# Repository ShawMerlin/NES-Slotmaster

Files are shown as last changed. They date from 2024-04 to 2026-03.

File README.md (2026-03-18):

06/25/2024 <br>
- Laser Bear has made an incredible interconnect flex cable.  I invite all to check this out!! <br>
- https://www.laserbear.net/products/nes-slotmaster
- https://x.com/dubesinhower/status/1805235309203845310/photo/1 <br>


 <br> <br>
06/15/2024 <br>
- We have a new solution that is 100% based upon J D'Silva's Ampersand Board. <br>
- J D'Silva was kind enough to let his design be used for our solution.  Give this guy some love!! https://twitter.com/jdsilva <br>
- No Longer Available from PCBWay (3/18/2026)

 <br>

 <br>

 <br>
 <br>
05/31/2024 <BR>
- 2 solutions have been developed and are currently being tested.  If you would like to help with the testing, please reach out through email. <BR>
- Laser Bear developed a [Flex cable](https://twitter.com/collingall/status/1795501525734768719) for the interconnect which allows better GND Coupling of the signal traces. <BR>
- J D'Silva developed a [interconnect board](https://github.com/J-DSilva/NES-Ampersand) which will also provide better GND Coupling. <BR>
- Check out the [Ninten-Drawer](https://twitter.com/RockerGameMod/status/1784955436606673254) as well for an alternative solution that solves the death grip issue in a very unique way. <BR>

J D'Silva's NES Amerpsand's solution means you do not have to replacet he current PCB's if you have already ordered them. <BR>
If you are a DIYer, this solution will be the most cost effective while Laser Bears solution is very elegant if you are not into DIY. <BR>

Here is some of my work with J D'Silva's NES Ampersand




 <BR>
 <BR>

05/17/2024 <BR>
- We are aware of potential issues with some EverDrive N8 Pro CARTs and the Slotmaster. <br>
- Issues can range from freezing, graphical artifacts and just plain refusing to boot. <br>
- It seems to be Hit or Miss when it comes to folks Everdrives. We have lots of reports of some working fine. <br>
- We are working on a solution so that more Everdrives will work.  More to come. <br> <br>

05/01/2024 <BR>
- New FPC Flex Slotmaster PCB Annoucement.  There is a seperate folder now for Flex version vs DIY Version. <br>
- Both Flex and DIY Versions have added footprints for ATTiny so a Krikzz AVRCIC can be used (if desired) <BR>
- DIY Version now has a 8 pin breakout that will help connect all 72 pins. (if desired) <br> <br>

04/22/2024 <BR>
- New Version 1.8 Board that ensures better game compatibility. Gerbers Above<br>
- We have a quick fix for anyone with that wants better compatibity with the V1.7 Board <br>
  This issue will not impact the majority of NES Game titles out there, but could impact a few. <BR>
  https://github.com/ShawMerlin/NES-Slotmaster/blob/main/Slotmaster%20DIY%20Version/Better_Compatibility_Fix.md <BR> <BR>

04/17/2024 <BR>
- FAQ information on the recent 3D Model and PCB change <br>
https://github.com/ShawMerlin/NES-Slotmaster/blob/main/SlotMaster_April_17th_Information_Update.pdf  <br>
- The Gerbers have been taken off Github as there is a small change that needs to be further researched. <BR>
- This change will not impact the majority of NES Game titles out there, but could impact a few. <BR>
- I plan to have everything tested and the new Gerbers released later this week  <BR>
- New SMD FPC Ribbon PCBs should arrive this week.  This design passes through all 72 pins. <BR>
- Laser Bear was gracious enough to share his changes to the 3d Model to provide more support.  This is V9 above <BR> <BR>

# NES Slotmaster

A fully open-sourced drop in replacement for the 72 Pin Cartridge Slot on a Front Loader NES. <BR> <BR>
if downloading Gerbers and STL is not your thing, both of these are included in my PCBWay Project. <BR>
https://www.pcbway.com/project/shareproject/NES_Slotmaster_bc9ea5b8.html <BR>
https://www.pcbway.com/project/shareproject/NES_Slotmaster_3D_Base_02da723d.html <BR> <BR>

Laser Bear is also offering these pre-ordered as a kit from his website <BR>
https://www.laserbear.net/products/nes-slotmaster <BR>

 <BR>
# Features of the NES Slotmaster
- Open sourced, build it yourself, make changes, the world is your burrito. <BR>
- No modification is need to your NES Console. Just enough skill to remove the top portion and swap the connector. <BR>
- Uses an existing 72 pin Connector. (Designing a brand new connector is not in my wheelhouse) <BR>
- The NES Cartridge is held close to the door of the NES so it's easy to grab and remove from the console. <BR>
- Minimul components, this can be built for less than $20. <BR>
- PCB uses a through hole design so this will be easier to solder for beginners.  I great first project. <BR>
- Can be used with the RF Shielding on the top and the bottom if desired, there is plenty of clearance. <BR>

<Br>
The 3D Model for this design was influenced by malleetech123 on Thingiverse and built using Autodesk Fusion 360. <BR>
I recommend using 100% in-fill with FDM printing for strength or print in resin. <BR>
A design using FPC Cables is in the works, it won't be as beginner friendly but will have less holes to solder. <BR>
<Br>
<Br>
















<br>
Clearance of the top and bottom shield <Br>







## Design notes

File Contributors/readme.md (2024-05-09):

# Contributors <br> <br>

Below is everyone that helped with the development of the Slotmaster.   Please show them all some love!! <br> <br>

- George from Long Island Retro Gaming for helping test the design. <br>
    https://www.youtube.com/@LIRetroGaming/videos <br>
 <br> <br>
- Project Guardian for being my design partner and my voice of reason. <br>
     <br> <br>
- Greg from Laser Bear for improving the 3D Model and offering DIY Kits <br>
    https://www.laserbear.net/products/nes-slotmaster <br>
     <br> <br>
- Muramasa for providing a slick easy to read schematic. <br>
    https://www.muramasaentertainment.com/ <br>
    
 <br>

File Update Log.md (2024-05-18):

## Known Issues <BR>
Certain Everdrive N8's are not booting or booting with graphical issues. (5/14/2024) <br>
- This is impacted with the V1.8 board versions. <br>
- The issue is not due to the 8 expansion pins on the header cable. That was incorrect information applied to the silkscreen. <br>
- This is currently being researched to find the differences and what the root cause of this. <br>
- ~~Potentially a Power draw issue with the size of the traces~~, also might be related to the ribbon cable being too long. <br>
- Potential of an issue with Noise/EMI getting into the data signal.  We are currently working on improving GND Coupling. <br>
- Some Everdrives N8 Pro's are working fine without issue.  We are keeping track of the ratio while we work on a solution.<br> <br>

Some cartridges are not compatible <br>
- https://github.com/ShawMerlin/NES-Slotmaster/blob/main/GamesNotCompatible.md <br>

Slotmaster V1.7 doesn't connect Pin56 <br>
- https://github.com/ShawMerlin/NES-Slotmaster/blob/main/Slotmaster%20DIY%20Version/Better_Compatibility_Fix.md <br> <br>

## Flex Version 1.8b <BR>
On Hold until Everdrive Issue is resolved. <br>
- Uses SMD FPC Flex connectors so that flat cables can be used.  Far less soldering. <br>
- Has a footprint for a ATTiny13 so the Krikzz AVRCIC can be used (if desired). <br> <br>

## DIY Version 1.8d <BR>
Gerber Files are available the under Slotmaster DIY Version folder <br>
- Includes the 8 pin breakout of all expansion ports so all 72 pins can be connected <br>
- Has a footprint for a ATTiny13 so the Krikzz AVRCIC can be used (if desired). <br> <br>

## Version 1.8 <BR>
Released 04/22/2024 <BR>
- Connected Pins 15 (IRQ) and 56 (PPU-WR) to ensure 100% Game Compatibility <br>
- Added an 8 Pin Header (2x4) to the top and bottom board to connect the EXP ports (if needed) <br>
- Increased the trace size on the VCC & GND from .25mm to .5mm <br>
- Added a logo for Laser Bear who helped redesign the Cartridge Slot and who is also offering these kits for sale <br>
<BR> <BR>

## Version 1.7 <BR>
Released 03/31/2024 <BR>
- First Public Release <br>

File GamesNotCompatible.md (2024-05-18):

A recent issue with some games has been identified by [Aaron Perkins](https://github.com/aaronperkins) <br>
This shows certain games could have a type of cartridge which does not exetend the entire width of the pad to the edge. <br>
Instead, it goes down to a small trace that does not come into contact with the 72 pin connector. <br> <br>
This new cartridge style seems to be on later cartridges and might have had the shorter contacts to ensure the Power/GND pins contacted first. <br>
The little tail on the end is a result of the electroplating process and didn't have any impact on cartridge connections. <br> <br> 
Thank you to [RedHerring32](https://github.com/Redherring32) for the additional info <br>
<br>
A potential fix might be to cut off the tabs on both sides of the top 72 pin connector, the tabs the screws hold down.  <br>
I do caution though that without those tabs, more stress will be applied to the solder joints on the backs pins when pulling out cartridges. <br>
The Juice might not be worth the squeeze <br>
<br>
If you find one of these games, please reach out ot me so that I can include it on this page. <br>
<br>
List of known games that could have this cartridge <br>
- Some variations of Super Mario Brothers/Duck Hunt <br>
- Dragon Warrior (We have had 2 reports, 1 with the short pads and one with normal pads.) <br>
- Donkey Kong CLassic (1 report so far)
- 1942 (1 report so far)
- Adventures of Dino Riki (1 report so far)

<br>
Example of this type of cartridge <br>
 <br>
<br>

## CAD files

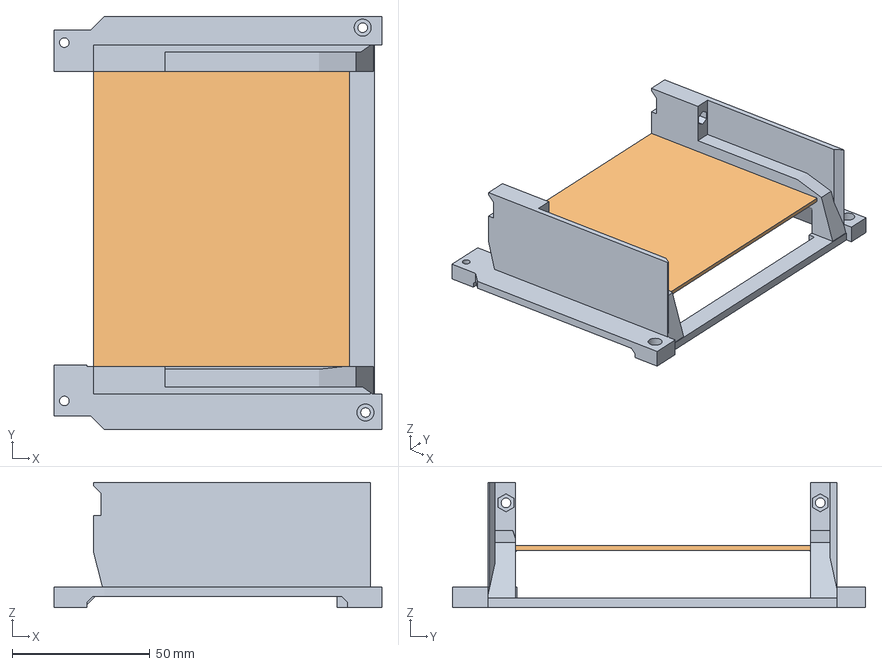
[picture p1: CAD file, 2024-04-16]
3D Model - NES Slotmaster (v9).3mf
119.0 x 150.0 x 45.5 mm
NES Slotmaster
Slotmaster bottom Cover

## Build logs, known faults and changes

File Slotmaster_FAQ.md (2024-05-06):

## Are these available for Pre-Order? <br>
Many people have reached out asking if they can sell these.  The MIT License allows for this to be sold. <br>
included in those people is Laser Bear who is taking Pre-Orders currently from his store <br>
https://www.laserbear.net/products/nes-slotmaster <br> <br>

## Can this be used with all the NES Shielding? <br>
Yes, A major part of this project was to get it to work perfectly with the shielding.  There is plenty of clearance. <br> <br>

## Why is there now a v1.8 SlotMaster PCB?
The SlotMaster v1.8 PCB corrects 2 pins, these were not used in v1.7 and should have been considered. With v1.8, now all NTSC NES Games will work with 100% compatibility. <br> <br>

## Is the Slotmaster V1.7 PCB still valid <br>
The v1.7 Slotmaster is still valid, it's just not 100% compatible with every single NES Game on the market.  <br>
We feel it's still valid as it will work with the majority of NES NTSC Titles. Onl<br>
If better compatibility is desired, please follow the 2 wire instruction guide that we will be providing soon. <br> <br>

## How can I get updates on new developments with this project <br>
In Github, you can click the watch button under the Slotmaster page. <br>
This will send you an email alert if any updates are maded to this repository. <br> <br>

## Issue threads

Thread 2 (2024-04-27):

1.7 fix instructions unclear

aaronperkins, 2024-04-27:
Love this project but I'm struggling with the 1.7 fix.

The schematic shows pin 15 to 29 but the photos show pin 15 to 27. Which is it? Also are we required to cut a trace? The schematic seems to indicate that, but it's not in the written instructions.

Thanks!

ShawMerlin, 2024-04-27:
The trace cut is not required as it's connected to a Expansion port pin.

You are correct that the pin I have marked and soldered to in my real life photo's is Pin 27 and wrong.  This should be on the one next to it.  Pin 15 is the IRQ which hardly any of North America NES's.  I will get the photo's updated to show the correct pin.

The critical one is pin 56 on the 72 pin connected to pin 32 on the 64 pin connector.
This is the PPU /WE and is the cause of the garbage artifacts that appear on some of the NES Games.

Thank you for pointing this out and i will get this corrected tonight.  Please follow the schematic and not the real life picture.

Thanks,
-Merlin Shaw

ShawMerlin, 2024-04-27:
Instructions have been corrected to show Pin 29 in the real photo's and not Pin 27.
Thank you again for finding this and raising the alarm.  :)

Closed 2024-04-27.

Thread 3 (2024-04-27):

Can't get some versions of Super Mario Duck Hunt to boot

aaronperkins, 2024-04-27:
I have quite a few copies of Super Mario Duck Hunt (don't ask why). I've been having trouble getting some to load with the Slotmaster. I get blinking light or character ROM corruption. Classic signs of a bad pin connection. The games are clean and known to work obviously.

I've narrowed it down to the versions of the game that have the weird "L" shaped pins. These are very common with later revisions of the game. See the attached picture.
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

I'm using the recommended 72 pin connector from Aliexpress. My guess is there is some sort of physical compatibility issue? The pins are too short to make proper contact with the connector?

I think I have other games beside SMBDH that have similar pins so I'm going to keep troubleshooting to verify the issue, but I wanted to bring it up here in case someone has run into this or knows better.

ShawMerlin, 2024-04-27:
Thank you for reaching out and providing the pictures.

Have you been able to look through and perform the 100% capability fix on
your Slotmaster  pcb’s?

I’m curious if some copies of duct hunt use the PPU /WE pin which is not
connected properly on the 1.7 version of Slotmaster.

If you have done the compatibility fix and still seeing this issue, please
reach out to my email. Merlin (dot) Shaw att gmail.

Thanks,
-Merlin Shaw

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

ShawMerlin, 2024-04-27:
Here is a link to the 100% compatibility fix

https://github.com/ShawMerlin/NES-Slotmaster/blob/main/Board%20V1.7%20100%25%20Compatibility%20Fix.md

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

ShawMerlin, 2024-04-27:
Doing some research on these carts with the L pads.  It does seem that Nintendo changed the carts in order to counter the clone units that were being developed.  Since we did not design that 72 pin connector, there might not be a solution for games with the L pads.

I would still check pin 15 & 56 on the CART to see if they are present or not.

aaronperkins, 2024-04-27:
Yeah I did the compatibly fix 1st thing. Didn't help. Nintendo messing with the pad design to stop counterfeit sounds like something they would do. I wonder if there are 72 pin connectors that work. I'll have to do some research. Thanks!

ShawMerlin, 2024-04-27:
If you do find any other 72 pin connectors out there, please reach out and
let us know.
The biggest issue is they have to be 2.5mm pitch while most connectors out
there are 2.54mm pitch.

So it has been very hard to find something compatible and I think we are
lucky enough to have these AliExpress ones.
But I am always 100% open to better options so if you find something.  Ring
the bell.  :)

Thanks,
-Merlin Shaw

On Sat, Apr 27, 2024 at 11:00 AM Aaron Perkins ***@***.***>
wrote:

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

aaronperkins, 2024-04-27:
Found a other game with short pads that won't work. This one is Dragon Warrior.
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

I confirmed with a multimeter no continuity between the short pads and the connector.

ShawMerlin, 2024-04-27:
Do you believe it’s every Dragon Warrior game cartridge or just the later
ones sold?

I can start a list of non compatible games on th le GitHub just so people
can realize that it’s not 100% compatible.

Thanks,
-Merlin Shaw

On Sat, Apr 27, 2024 at 4:13 PM Aaron Perkins ***@***.***>
wrote:

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

aaronperkins, 2024-04-27:
I have two copies of Dragon Warrior and they both have the same board with the short pads.

ShawMerlin, 2024-04-27:
I am going to get a coo of Dragon warrior to help visualize this for
myself.  Most likely there won’t be a solution quickly but I will add this
game to the potential issue list.

Thanks,
-Merlin Shaw

On Sat, Apr 27, 2024 at 5:42 PM Aaron Perkins ***@***.***>
wrote:

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

aaronperkins, 2024-04-28:
Found this potential solution. Going to try it when I have a chance.
[https://github.com/sanni/cartreader/issues/632](Link)

elgarlic, 2024-05-02:
Just out of curiosity, do these PCBs work in a Game Genie? Wondering for the sake of a stopgap fix (if it works) as well as whether this was another possible motivation for the design (if it doesn't).

aaronperkins, 2024-05-10:
Quick update.

Cutting the tabs off the 72 pin connector does seem to fix the issue, though I still wouldn't call the connection perfect. Sometimes the cart needs a little wiggle to get it working. Here are some pictures:

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

I used the tabs I cut off to space the screws otherwise they were now too long.

The game genie does also solve the problem as a work around:
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

You can see the game genie's connector allows the cart to slide back more compared to the slotmaster.

Finally I found another game with the same issue:
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
This one is Donkey Kong Classics

ShawMerlin, 2024-05-10:
thank you @aaronperkins for the pictures and analysis!! I will update our known issue document with Donkey Kong Classics as could be susceptible.

Interesting observation with cutting off the tabs, I should get my Dragon Warrior NES Cartridge this weekend and hope to get one of these short pad styles.

I will add your notes that cutting that tab might help.  I still wonder though if it's worth the effort when that tab having the screw hold it tight, helps the connector not pull so much on the back soldered pins.  Without that extra support, it might lead to some solder joints breaking in the future.  Just something to consider.

Thanks again!!

aaronperkins, 2024-05-10:
I have an old NES on my bench I use to test games. It gets a lot of cart inserts. We'll see how the tabless configuration works out.

I refurbish these consoles and really want to offer SlotMaster as an optional upgrade. If the games that didn't work were obscure I'd leave the tabs in, but I imagine the first cart my customers are going to try is SMB/DH.

Anyway, really appreciate the project and all the work you've put into this! Thanks again!

ShawMerlin, 2024-05-10:
Great points.  I'm sure if folks are worried about the solder joints they could just use epoxy around the connector which would make it one solid piece.  It wouldn't be as serviceable in the future but these are cheap enough that just replacing it quickly wouldn't be a big deal at all.

I'm curious what percentage of SMB/DH games have this edge.  I have 2 copies and both of mine are normal.  I wish there was more information out there about these.

aaronperkins, 2024-05-10:
Did I mentioned I had a quite a few copies? 😉

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

Of the 17 copies I have 11 have the short pads.

ShawMerlin, 2024-05-10:
That is quite a sample pool  :)   I will note on the issue page that most SMB/DH were found with the short pads.

ShawMerlin, 2024-05-11:
Ugg, my copy of Dragon Warrior that I ordered off eBay has the normal pads.  @aaronperkins, would you let me purchase one of your SMB/DH with the short pads?

aaronperkins, 2024-05-11:
I'll donate one to the project as a thank you. I'll send you an email to get shipping information.

J-DSilva, 2024-05-12:
FWIW, I checked my pile of cart PCBs, and of my 8 Mario/Duck hunts only 3 have short pads.

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
KPackratt2k, 2024-12-22:
I wonder if scraping off the green solder mask band on the bottom of the pins on the affected cartridges would improve compatibility. It's possible that the solder mask is preventing the cartridge slot from making contact with the pins on the edge connector. FWIW I took apart every single one of my NES cartridges and found a couple games (Tetris and SMB2) with the green band. I was able to scrape off the green band carefully with an exacto knife and cleaned off the excess solder mask powder using q-tips dipped in 91% isopropyl alcohol. This improved compatibility with these games on a 72-to-60 pin adapter that was having issues with them, so I would imagine it could make an improvement for Slotmaster users.

Otherwise, another option would be to desolder the chips from the cartridge PCB and transplant them to a new PCB with a different pin shape. For SMB and Duck Hunt copies with epoxied chips, it may be necessary to wire an adapter to the cartridge PCB to act as an interposer between the NES and the cartridge PCB. I plan on designing a PCB that could be used for this purpose at some point.

aaronperkins, 2024-12-22:
@KPackratt2k if you rather not modify your vintage game carts, cutting the tabs off the 72 pin connector as mentioned above has been working pretty well for me.

Some carts need a little wiggle to get them to connect but I haven't found one yet that won't work. I've probably done hundreds of insertions over the past 6 months and the solder joints seem to be holding up just fine without the tabs.

WarlordZen, 2024-12-22:
I found a permanent fix for this. Not sure it is ideal but it works. Before soldering the game side connector, I pushed the pins in the connector out so instead of the pins sticking out of the board they are flush with the board. I only did this on the side the short pins where on. So far all games work.

ShawMerlin, 2024-12-22:
Great feedback everyone!! I will try and get all of info on the GitHub
page.  There is a lot to information which is very appreciated.

WarlordZen, do you happen to have any photos of what it looked like after
you pushed out those pins?

Thanks,
-Merlin Shaw

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

WarlordZen, 2024-12-22:
I don't but I can.

my2k2zx2, 2025-01-25:
> I don't but I can.

Pic would be great.  I can't seem to get any pin to move in the connector I bought.    Not sure what the truck is.

otacon6530, 2025-02-23:
I bought the slot master flex, so I am not sure about the differences, but my games wouldnt work with the slot even if I removed the cartridge housing, so cutting off the tabs wouldn't have worked for the slot Laser Bear used. I suggest doing this step before cutting to verify if it will fix the issue for you.

I replaced it with with an avr connector instead (https://www.retrousb.com/product/nes-connector/36), which is deeper and should just work for normal slot masters.

If you have the eject button you will need to cut the notch the conector pcb attaches to until it is flush with an inserted cartridge. The eject button is designed for the original connector and prevents the cart from seating all the way.

aaronperkins, 2025-02-23:
I just wanted to vouch for the @WarlordZen solution. Worked like a charm!

I used the Slotmaster board as a guide and a plastic flat tool to push the pins flush to the board. See pictures.

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

otacon6530, 2025-02-23:
I will give it a try on my second nes. Thanks

otacon6530, 2025-02-24:
@aaronperkins Did you just do the bottom pins or all pins?

my2k2zx2, 2025-02-24:
I only did the top/cartridge side.  So far it's working perfectly on real carts.  Cant get my Famicom Everdrive to work with it, waiting on parts for the ampersand board to show up and give that a try.

aaronperkins, 2025-02-24:
> [@aaronperkins](https://github.com/aaronperkins) Did you just do the bottom pins or all pins?

Just the bottom row. I'm thinking I should have done the top and bottom row though. The carts tilt a little upwards with just the in bottom row.

otacon6530, 2025-02-24:
> > [@aaronperkins](https://github.com/aaronperkins) Did you just do the bottom pins or all pins?
>
> Just the bottom row. I'm thinking I should have done the top and bottom row though. The carts tilt a little upwards with just the bottom row.

Thats good to know. My 3d printer is down, but will get it up sometime in the next week to try it out myself.

my2k2zx2, 2025-02-26:
Ampersand board has arrived.  Can confirm that with this setup, my Famicom Everdrive with 60-72 adapter is now working perfectly with the Slotmaster.

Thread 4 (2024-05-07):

Bottom PCB clearance issues with Hi-Def NES using the Laserbear No Cut Kit

pmgducati, 2024-05-07:
Hello,
I am working on the DIY (1.8c) version of the slotmaster and have run into a clearance issue.  I have the Hi-DefNES Kit (https://www.game-tech.us/product/hi-def-nes/) and using the Laser Bear No Cut Kit (https://www.laserbear.net/products/nes-front-loader-hi-defnes-no-cut-kit).  The bottom PCB does not have clearance to install with the Hi Def PCB install Location.  I was able to make it fit by trimming your PCB down leaving ~1mm below the 8 Pin header traces.  Would you consider updating the PCB to allow for this?  Im happy to help test fit PCBs.

Here are some picture of the modifications that I had to make to the PCB:
Mounted in the NES:
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
Loose:
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
Measurements:
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

ShawMerlin, 2024-05-07:
Thank you for the pictures and measurements.  I will make updates to the board so that they will accommodated the Hi-Def Mod.

pmgducati, 2024-05-07:
Thanks!

ShawMerlin, 2024-05-07:
How does this look?  If you can send me an email, I will send you the gerbers.  merlin (dot) shaw at google

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

pmgducati, 2024-05-08:
Email sent!

ShawMerlin, 2024-05-18:
Our new boards will have the shorter bottom so this will not be an issue going forward.
Thank you again for bringing this to our attention.

Closed 2024-05-18.

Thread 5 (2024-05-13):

Potential issues with an Everdrive Cart

ShawMerlin, 2024-05-13:
We have had a few reports of issues when using an Everdrive Cartridge.

This is being looked at currently to see if a root cause can be found.
It might be because the ribbon cable is long and there is more distance than the stock connector.

I am opening this issue in case others want to share their experience on here and to keep updated on our progress.

Thanks,
-Merlin Shaw

dbstallman1, 2024-05-13:
Here has been my experience - I purchased three Slotmasters from LaserBear.  I installed the first one and my EverDrive N8 with latest firmware appeared to work until a game was played.  It would then lock up or have graphical glitches within a minute or two.  I installed the second one the same night and the Everdrive seemed to work correctly.

Then next day I installed the third and that system would not recognize the Everdrive cart at all, and when going back to the other two systems they no longer would boot either.  I saw on the product page that the 8 pin header was needed for proper operation, so I ordered the headers and interconnects.  When they arrived I added them and tried again.

The first system still boots the Everdrive, but gives alternating error codes - SD card initialization failed or SD card not formatted.  I will add that this Everdrive continues to work perfectly in my top loader.  The second and third systems will now do the blinking light and reset.

All three systems work with any other cart (beyond Dragon Warrior) that I put in them.  The success with the Everdrive has been failure far more often then working.

ShawMerlin, 2024-05-13:
I think the issue you are experiencing is due to an earlier Gerber file that had thinner traces.  This results in not enough power getting into the Everdrive Cartridge.

If you are able, bodge the power pins from the 72 pin to the 64 pin connector so that it will provide more current.
From looking at the back of the boards, it will be the 2 pins on the left and the bottom pin on the far right.

Let us know if that solves this issue.

Here is a picture of the Power Traces, they are twice as thick.  check your boards to see what size they are compared to the other traces.
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

dbstallman1, 2024-05-13:
From a cursory glance they appear to be the same size.  I have v1.8 of the boards.

I'm heading out for an hour or so right now, but I can definitely get this done on at least one of them tonight. Reinforcing the connections on both sets of PCBs is what is best, correct?

ShawMerlin, 2024-05-13:
Yes, use a wire between the thicker trace points above on the 72 pin and connect to the related pad on the 64 pin.  By reinforcing with a wire, this will allow for the higher current for the Everdrive to pass through and should resolve your issue.

dbstallman1, 2024-05-14:
I've added reinforcement jumpers to all three pins on the top and bottom boards on one of sets.  Unfortunately, it didn't make a difference.  All other carts still work.  I'll do the mod to the other two tomorrow night to see if that makes a difference on them.

So far, though, no success.

ShawMerlin, 2024-05-14:
I did explain one of the top pins wrong and I believe you reinforced the System CLK and not the GND Pin.  Here is a diagram showing the top board from the front.  On the left, the top pin should be reinforced to the top pin on the IDC connector.

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

dbstallman1, 2024-05-14:
I actually couldn't remember which side was only one pin once I was at the workbench.  Rather than go back and check, I reinforced pins 1, 36, 37, and 72.  So that means I did the correct ones anyway.

ShawMerlin, 2024-05-14:
Thank you for following up with that.  I will see if I can get to the bottom of this issue.  If you can send me an email  merlin (dot) shaw at google.  I will make sure to send you a board to test.

ShawMerlin, 2024-05-18:
At this point.  We feel that it's a Noise/EMI issue with the Data lines becoming corrupted.  This could be due to the longer cable but we are seeing it as well with a shorter cable.

Some Everdrives work fine with no issue so it's very hit or miss.  We are working on a solution that will improve compatiblity with Everdrive Carts.  Our goal is to have the same compatibility as an Everdrive with the original connector.

I will update this thread when we have more news on this.

ShawMerlin, 2024-06-15:
Thank you everyone for the support!!  We have our new solution here and I will be sending it to everyone that was willing to test for us.  If you have not already, please get me an email with your address so I can send you one -

Here is the IDC Cable Replacement
https://github.com/ShawMerlin/NES-Slotmaster/tree/main/NES_Ampersand

Tzibu, 2024-06-15:
***@***.*** ***@***.***>  please 😊

Lähettäjä: Merlin Shaw ***@***.***>
Lähetetty: lauantai 15. kesäkuuta 2024 19.20
Vastaanottaja: ShawMerlin/NES-Slotmaster ***@***.***>
Kopio: Subscribed ***@***.***>
Aihe: Re: [ShawMerlin/NES-Slotmaster] Potential issues with an Everdrive Cart (Issue #5)

Thank you everyone for the support!! We have our new solution here and I will be sending it to everyone that was willing to test for us. If you have not already, please get me an email with your address so I can send you one -

Here is the IDC Cable Replacement
https://github.com/ShawMerlin/NES-Slotmaster/tree/main/NES_Ampersand

—
Reply to this email directly, view it on GitHub <https://github.com/ShawMerlin/NES-Slotmaster/issues/5#issuecomment-2170122847> , or unsubscribe <https://github.com/notifications/unsubscribe-auth/BIJQ3VCBDHHF7RBJFPK52CLZHRST7AVCNFSM6AAAAABHU6RHD2VHI2DSMVQWIX3LMV43OSLTON2WKQ3PNVWWK3TUHMZDCNZQGEZDEOBUG4> .
You are receiving this because you are subscribed to this thread.  <https://github.com/notifications/beacon/BIJQ3VCNQZ32WCOHCYWRO6DZHRST7A5CNFSM6AAAAABHU6RHD2WGG33NNVSW45C7OR4XAZNMJFZXG5LFINXW23LFNZ2KUY3PNVWWK3TUL5UWJTUBLFZF6.gif> Message ID: ***@***.*** ***@***.***> >

ShawMerlin, 2024-06-15:
It masks your email address, you will have to email me.  I'm sure if you
look hard enough, you can find my email ;)

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

otacon6530, 2025-06-11:
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

Could it be short pinned or banded?

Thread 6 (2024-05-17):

Crashing games feedback

Dan15ks, 2024-05-17:
I have the 1.8 from laserbear, I've tested about 15 games for far all original carts. Megaman 2 crashes Everytime at the stage select screen. Castlevania crashes after the first level. Both games worked flawless before the slotmaster.

ShawMerlin, 2024-05-18:
Thank you for the report.  I have noted those game titles.
At this point, I think it would be the same issue as why some of the Everdrive N8 Pro's are freezing/crashing.

We are currently working on a solution and I will update this and the other issue threads when we have a replacement.

Thanks,
-Merlin Shaw

freakmanultra, 2024-06-03:
I just built 5 of the 1.8 slotmaster. I have not had any problems so far with real carts and the clone flashcarts. I have my on an RGB modded NESessity v1.6.
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

ShawMerlin, 2024-06-03:
Thank you for this feedback!!  It is very hit and miss with what works and
what doesn't work.
My original Everdrive N8 Pro worked so I ordered another one hoping to get
one that doesn't work and the new one worked too.

There are so many variables with this older hardware.  Add to that modern
hardware and even a difference in MicroSD Cards.

We want our Slotmaster solution to work with all Everdrives, no matter the
variables so we are still working on final solution.
But I am happy to hear your setup is working and that it's working with the
NESessity  :)

Have a fantastic day.

Thanks,
-Merlin Shaw

On Mon, Jun 3, 2024 at 11:12 AM freakmanultra ***@***.***>
wrote:

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

freakmanultra, 2024-06-04:
> Thank you for this feedback!! It is very hit and miss with what works and what doesn't work. My original Everdrive N8 Pro worked so I ordered another one hoping to get one that doesn't work and the new one worked too. There are so many variables with this older hardware. Add to that modern hardware and even a difference in MicroSD Cards. We want our Slotmaster solution to work with all Everdrives, no matter the variables so we are still working on final solution. But I am happy to hear your setup is working and that it's working with the NESessity :) Have a fantastic day. Thanks, -Merlin Shaw
> […](#)
> On Mon, Jun 3, 2024 at 11:12 AM freakmanultra ***@***.***> wrote: I just built 5 of the 1.8 slotmaster. I have not had any problems so far with real carts and the clone flashcarts. I have my on an RGB modded NESessity v1.6. PXL_20240601_010704424.jpg (view on web) <https://github.com/ShawMerlin/NES-Slotmaster/assets/171604687/8c19eddb-19b6-458f-b7d2-d786e0dd8322> PXL_20240601_010722633.jpg (view on web) <https://github.com/ShawMerlin/NES-Slotmaster/assets/171604687/9d6f2321-fe7c-49cc-b349-0f664847b460> PXL_20240601_010758625.MP.jpg (view on web) <https://github.com/ShawMerlin/NES-Slotmaster/assets/171604687/2a2801b5-17f8-4025-b0e3-49c152d250f7> — Reply to this email directly, view it on GitHub <[#6 (comment)](https://github.com/ShawMerlin/NES-Slotmaster/issues/6#issuecomment-2145729435)>, or unsubscribe <https://github.com/notifications/unsubscribe-auth/AQZJHHV6IDBEIOEZIW6ZZZ3ZFSPXBAVCNFSM6AAAAABH3HV3WKVHI2DSMVQWIX3LMV43OSLTON2WKQ3PNVWWK3TUHMZDCNBVG4ZDSNBTGU> . You are receiving this because you commented.Message ID: ***@***.***>

If you need any more testers, let me know. I would love to helo the project. I have 2 other NES systems that are currently stock.

ShawMerlin, 2024-06-15:
Thank you everyone for the support!!  We have our new solution here and I will be sending it to everyone that was willing to test for us.  If you have not already, please get me an email with your address so I can send you one -

Here is the IDC Cable Replacement
https://github.com/ShawMerlin/NES-Slotmaster/tree/main/NES_Ampersand

Dan15ks, 2024-06-15:
goligoski3@gmail.com is my email, I like to do some testing if possible.

freakmanultra, 2024-06-15:
***@***.***
I have 5 slotmaster 1.8  built I can test it on.

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

ShawMerlin, 2024-06-15:
Github masks out email addresses so you will have to send me an email
directly.
If you look under the GND Loop issue document on my NES Power Boards
Github, I have my email listed there.

I can send you 5 interconnect boards.

Thanks,
-Merlin Shaw

On Sat, Jun 15, 2024 at 2:50 PM freakmanultra ***@***.***>
wrote:

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

freakmanultra, 2024-06-22:
I was having some freezing issues with my Super C cart with the Ampersand. With the way everything is "squished together" it seemed like a connection somewhere was not connecting properly.  My fix was to  cut a little plastic away on the 3d printed mount by the 8 pin connector. The solder joints were hitting and causing the board to flex a bit when everything was tightened down.  Super C has been running in demo mode for a bit now with no issues. I was even able to get through the entire game.
This is on my NESessity v1.6 build.

Left side first mount attempt.
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
Right Side of mount - Solder joints on 8 pin hitting 3d printer bracket

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

Final Fit after trimming and assembling.
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

This is slotmaster #2 that is about to be installed on an unmodified system. Same "8pin" rubbing
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

ShawMerlin, 2024-06-22:
Thank you for the detailed write up and the photos!!

We have been looking at an option to make more room for those pins.  We also had the idea of using a SMD 8 pin connector like this (https://www.ebay.com/itm/183420909073) to make it so no pins are on the backside at that point.

the Ampersand fit is very tight so I will be moving it slightly up on the bottom so that it's not as tight, but the issue of the pins on the back of the 8 pin connector is still something that will be fixed as well.

Thanks again for everything,
-Merlin Shaw

freakmanultra, 2024-06-22:
Easiest solution seems to just make a "Notch" in the STL file for the 8 pin.

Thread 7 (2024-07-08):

Possible Incompatiblity with Ducktales

Sowden, 2024-07-08:
Hey guys.  I wanted to check if anyone else here is having trouble with Ducktales.  I had a No Light Blink Win in my machine before and it played every time.  I'm pretty sure that my cart is good.  Can anyone else confirm this?  Thanks guys.

ShawMerlin, 2024-07-08:
I have not heard of Ducktales not working,  does this CART have the short
pads on it like some of the other ones that aren't working?
Also, the Blinking Light Win bypasses the CIC chip while the Slotmaster
does not, so if the light is blinking, there might be a connection or issue
with the CIC.

Thanks,
-Merlin Shaw

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

Sowden, 2024-07-12:
So I just got home and tried it again.  Like I said I have a Hi-Def NES internally installed.  So games that don't seat well gives me a grey screen.  So I tried it again this morning and got the same thing.  But the red LED light was on solid red.  So I don't know what that means.  My buddy had a NES cart screw driver, and I can open it up to take a look at the board, but I'm not quite sure what I'm looking for.  If I take a picture and post it here, could you tell if it's a cart with short pins or not?

Sowden, 2024-07-25:
Alright, so I was able open up my cart and take some photos.  Is this what you need to determine if this cart is compatible or not?  Also for the record, my copy of 1942 works with my Slotmaster, so 🤷
![Uploading IMG_20240720_092144191.jpg…]()
![Uploading IMG_20240720_092150207.jpg…]()
![Uploading IMG_20240720_092252082.jpg…]()
![Uploading IMG_20240720_092303211.jpg…]()

Sowden, 2024-07-25:
Alright, so I was finally able to open my cart and take some photos.  This is my original cart I had as a kid, and I want to say I bought it pretty early on, but can't say for sure.  Is this what you need to determine if it's compatible or not?  Also to put on the record, my copy of 1942 worked on my Slotmaster, so 🤷

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

aaronperkins, 2024-07-29:
Looks like another cart with short pads. I've been documenting this issue here: https://github.com/ShawMerlin/NES-Slotmaster/issues/3

ShawMerlin, 2024-07-29:
I have not ever seen one where it's the long pads on one side and shorter on the other.  It's worth noting that on the above picture, the short pads are not as short as the previous ones we have seen but not the full length either, it's sorta inbetween.  Thank you for documenting this!

Sowden, 2024-07-30:
Ahh geez, that's a tad bit disappointing.  But if the rest of my games work, then that's a pretty good deal.  Thanks guys, glad I could help out

ShawMerlin, 2024-07-30:
Im looking an option for folks that want to use their short cart games with
one of these aftermarket ports that they could swap the chips onto a brand
new PCB. It’s not 100% genuine anymore but at least the chips are still
legit and genuine and the games can be used.

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

Sowden, 2024-07-31:
Oh a board swap out would be great.  Would it come from PCBway?  And would there be any soldering involved?  And thanks for working so hard for us.

ShawMerlin, 2024-07-31:
Yes, it would be easily order-able from PCBWay and then you would just
desolder the chips and put them on the new PCB.

I hope to have the first prototype here in a few weeks and can send you
some if you shoot me an email.

There are a lot of variations of CART PCBs so they would be game specific.
I will have a cross reference chat that lists which games the board
supports.

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

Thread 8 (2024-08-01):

Megaman 1 PAL B Eur version incompatible

PeteCologne, 2024-08-01:
The PAL B version of Megaman 1 also has a UNROM-08 board with the short pins. The game doesn't work - only got it to work when inserting the pcb alone.

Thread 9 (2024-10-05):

3D Print files are not compatible with PCBWAY

Tz1rf, 2024-10-05:
Tried to order the 3D print of the Slotmaster Cartridge Unit on PCBway from the link in the description. You cannot order it as the file type (7z file) is not suitable for 3D Printing. Is there a compatible file type (STP, STEP, STL or OBJ) available?

ShawMerlin, 2024-10-05:
We have the first rendition still in our GitHub I believe.  That one is a
Stl file.  I will have to see what is going on with that.

Thanks for letting me know.

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

Closed 2024-11-04.

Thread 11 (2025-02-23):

The Guardian Legend not working

otacon6530, 2025-02-23:
I am just letting you know that The Guardian Legend is a short pin (green stripe) cartridge that doesn't seem to work on the slot master.

I took Dragon warrior and The Guardian Legend out of their cases and they still don't work, so I don't think the proposed "Cutting off the tabs" will work, at least in my case, because the case wasn't a factor. Instead I solved the issue by making some modifications to the slot master and replacing the cartridge connector with something a bit deeper. I put the details in the discussions section and will provide images, new 3d part designs and more details soon.

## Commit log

2024-03-31 Create Bill of Material (BOM).md
2024-03-31 Update Bill of Material (BOM).md
2024-04-23 Create Board V1.7 100% Compatibility Fix.md
2024-04-27 Update Board V1.7 100% Compatibility Fix.md
2024-05-04 Create 8 Pin Expansion Header.md
2026-03-18 Add product link for Laser Bear NES Slotmaster
    Added a link to the Laser Bear NES Slotmaster product.
